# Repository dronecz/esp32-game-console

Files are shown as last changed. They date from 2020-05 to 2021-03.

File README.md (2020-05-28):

# ESP32 game console 

You can read more about my project [here](https://hackaday.io/project/166873-esp32-game-console) at Hackaday.io . :slightly_smiling_face:

This repository contain PCB files and 3D files for ESP32 game console. 

In case that you will have any question, you can contact me at info@czechmaker.com

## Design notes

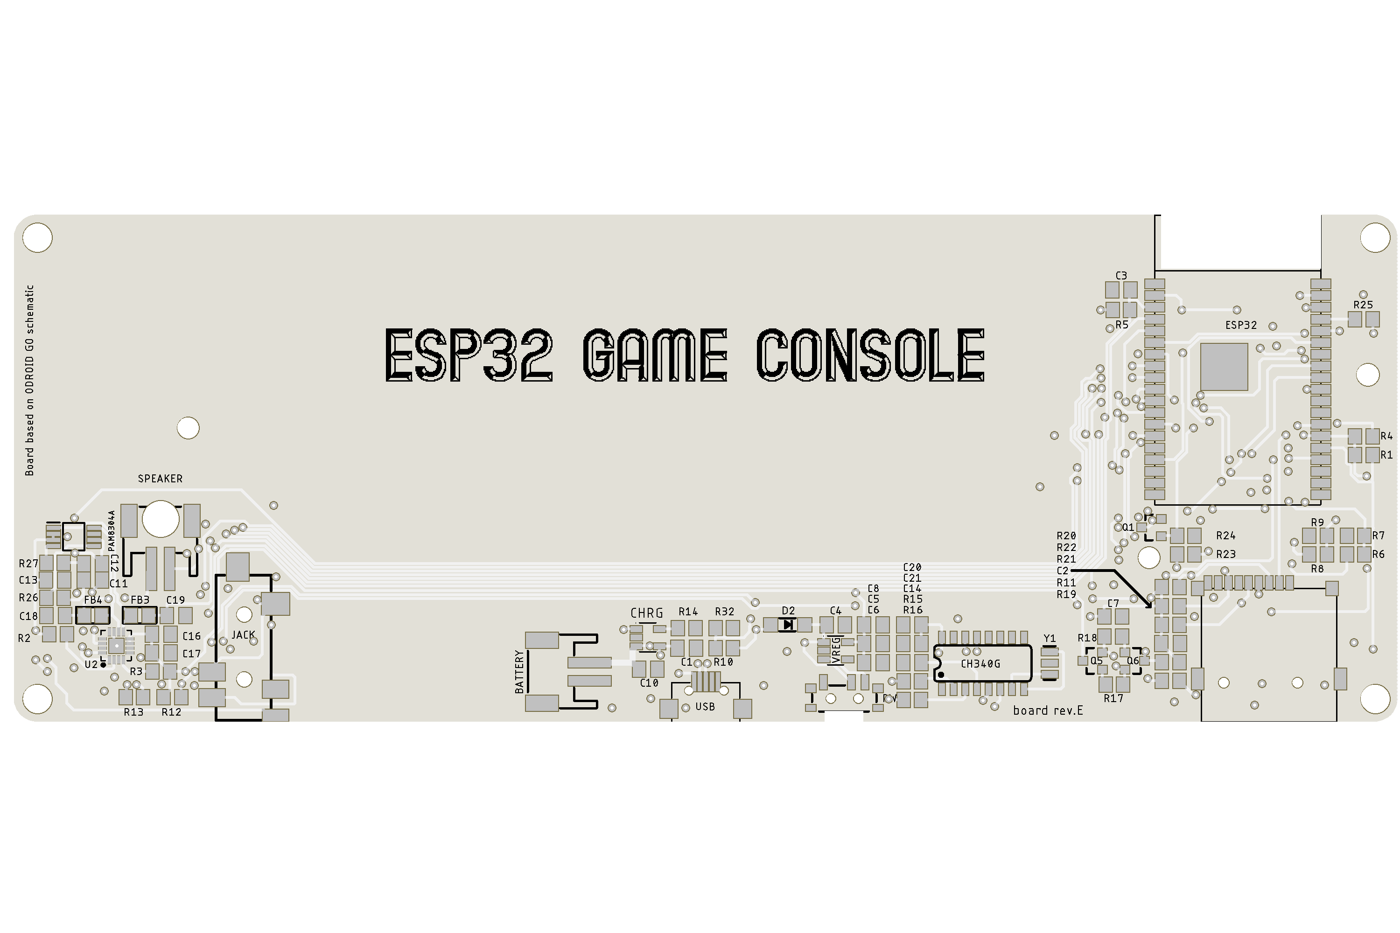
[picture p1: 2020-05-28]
PCB/rev_E_buttons/o_clone_rev_e_bottom.png

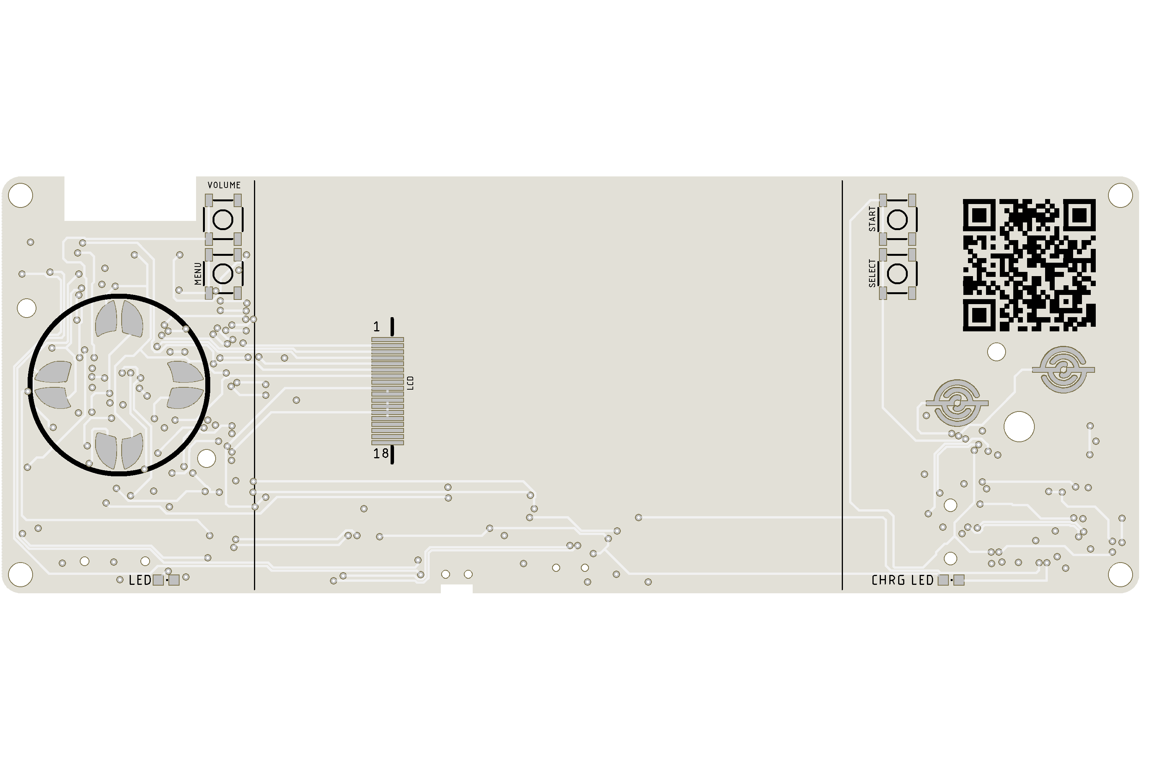
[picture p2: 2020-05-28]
PCB/rev_E_buttons/o_clone_rev_e_top.png

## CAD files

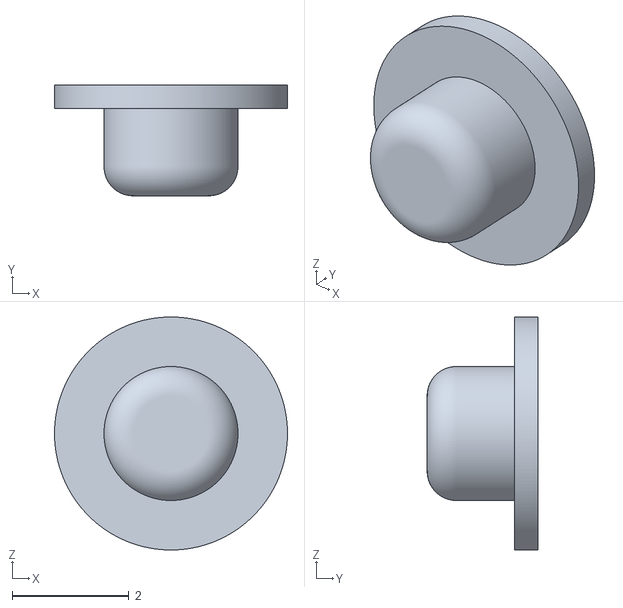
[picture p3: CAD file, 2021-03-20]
3D files/rev_F/esp32_gc_power_button_rev_F.stl
4.00 x 1.90 x 4.00

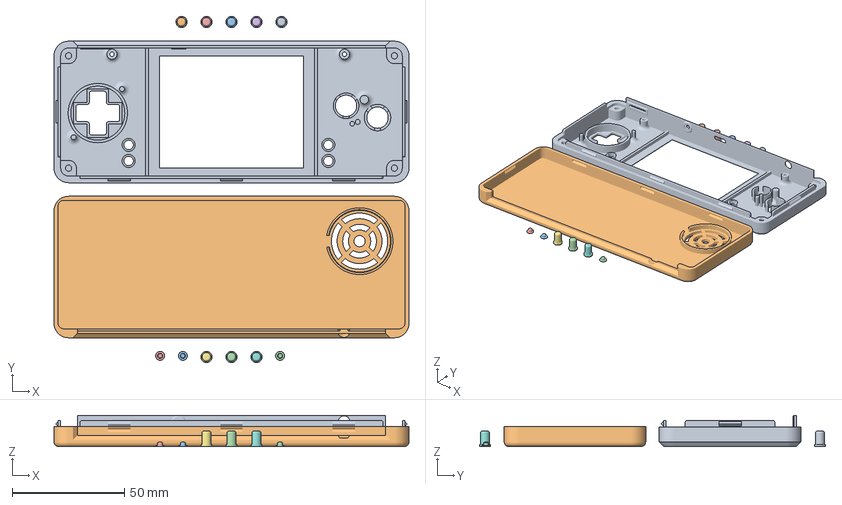
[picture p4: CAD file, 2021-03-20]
3D files/rev_F/Case_Odroid_Go_clone_rev_F.3mf
158.0 x 154.1 x 13.8 mm
top_case.stl
bottom_case.stl
eps32_gc_button_rev_F.stl
power_button.stl

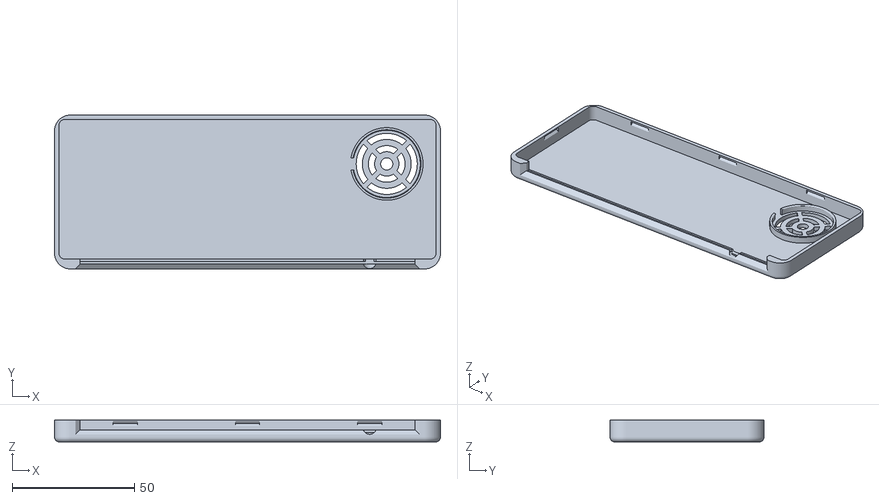
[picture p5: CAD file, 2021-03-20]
3D files/rev_F/esp32_gc_bottom_case_rev_F.stl
158.0 x 63.0 x 9.00

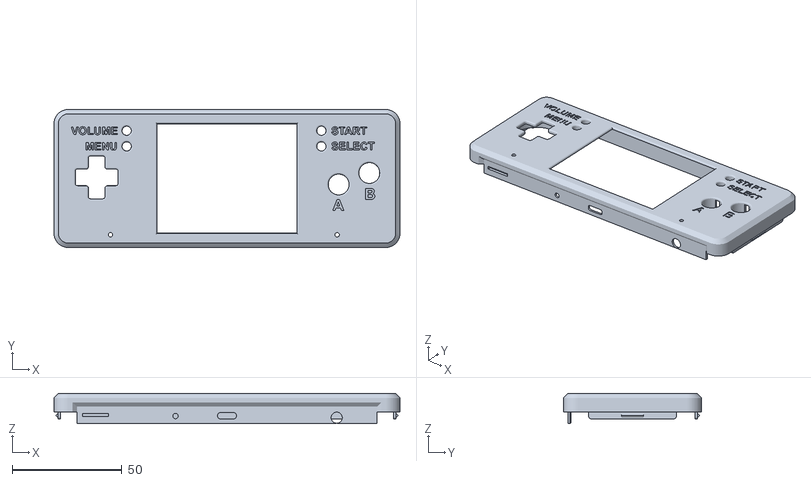
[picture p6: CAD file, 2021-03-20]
3D files/rev_F/esp32_gc_top_case_rev_F_letters.stl
158.0 x 63.0 x 13.8

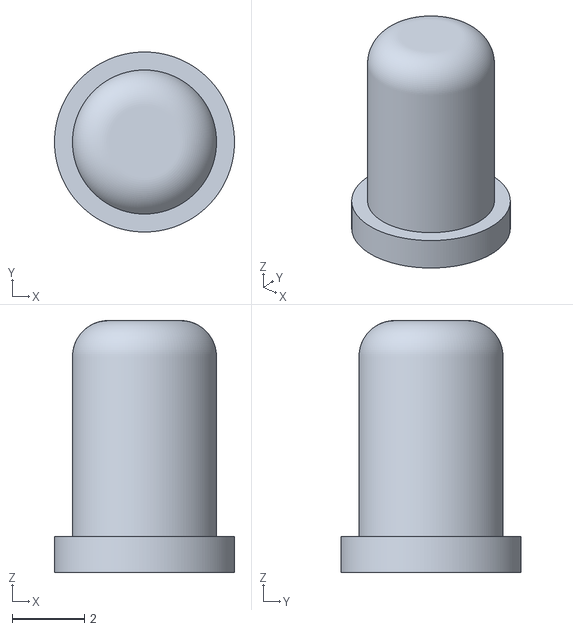
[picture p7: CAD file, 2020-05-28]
3D files/rev_F/eps32_gc_button_rev_F.stl
5.00 x 5.00 x 7.00

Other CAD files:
3D files/rev_F/esp32_gc_top_case_rev_F.stl

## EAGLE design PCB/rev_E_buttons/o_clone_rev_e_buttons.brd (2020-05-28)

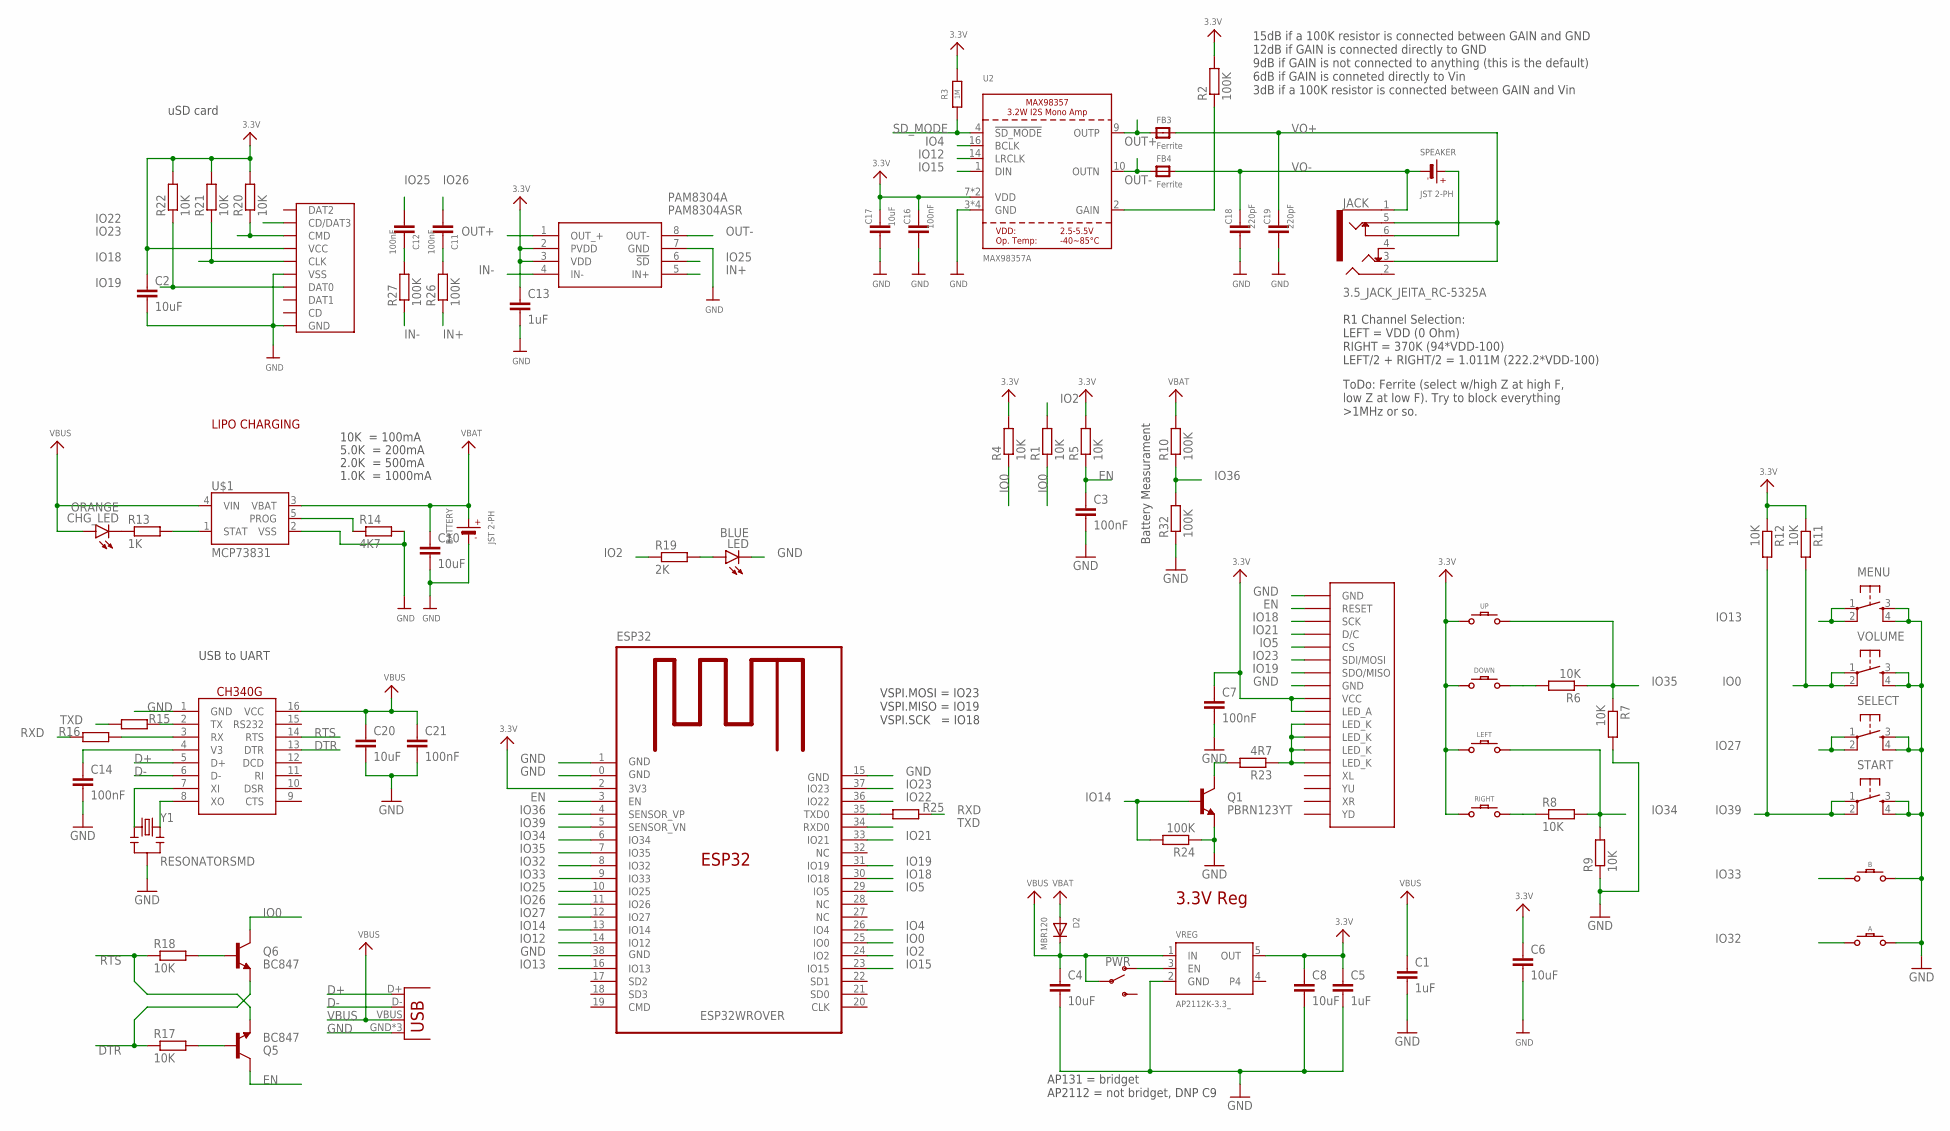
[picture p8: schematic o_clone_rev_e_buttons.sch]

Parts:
A: CONDUCTIVE_BUTTONCONDUCTIVE_BUTTON_THICK; CONDUCTIVE_BUTTON_THICK
B: CONDUCTIVE_BUTTONCONDUCTIVE_BUTTON_THICK; CONDUCTIVE_BUTTON_THICK
BATTERY: JST 2-PH; JSTPH2
C1, C5, C13: 1uF; C0805K
C2, C4, C6, C8, C10, C17, C20: 10uF; C0805K
C3, C11, C12, C14, C16, C21: 100nF; C0805K
C7: 100nF; C0805
C18, C19: 220pF; C0805K
CHG_LED: ORANGE; CHIPLED_0805
D2: MBR120; SOD-123
DOWN: CONDUCTIVE_BUTTONCONDUCTIVE_BUTTON_DIRECTIONAL_TH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; CONDUCTIVE_BUTTON_DIRECTIONAL_THICK
ESP32: ESP32WROVER
FB3, FB4: Ferrite; 0805
JACK: 3.5_JACK_JEITA_RC-5325A
LCD: ILI9341_3.2LCD_; LI9341_3.2LCD
LED: BLUE; CHIPLED_0805
LEFT: CONDUCTIVE_BUTTONCONDUCTIVE_BUTTON_DIRECTIONAL_TH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; CONDUCTIVE_BUTTON_DIRECTIONAL_THICK
MENU: TACTILE_SWITCHE_5X5_MICRO"; TACTILE_SWITCH_5X5_MICRO
PAM8304A: PAM8304ASR; SOP65P490X110-8N
PWR: SWITCH-SPDT-SMD-RIGHT-ANGLE; SWITCH_SPST_SMD_A
Q1: PBRN123YT; SOT23-3
Q5, Q6: BC847; SOT23-3
R1, R4, R5, R6, R7, R8, R9, R11, R12, R17, R18, R20, R21, R22: 10K; R0805
R2, R10, R24, R26, R27, R32: 100K; R0805
R3: 1M; R0805
R13: 1K; R0805
R14: 4K7; R0805
R15, R16, R25: 470R; R0805
R19: 2K; R0805
R23: 4R7; R0805
RIGHT: CONDUCTIVE_BUTTONCONDUCTIVE_BUTTON_DIRECTIONAL_TH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; CONDUCTIVE_BUTTON_DIRECTIONAL_THICK
SD_CARD: MICRO_SD_CARD"; TFP09-2--12B
SELECT: TACTILE_SWITCHE_5X5_MICRO"; TACTILE_SWITCH_5X5_MICRO
SPEAKER: JST 2-PH; JSTPH2
START: TACTILE_SWITCHE_5X5_MICRO"; TACTILE_SWITCH_5X5_MICRO
U2: MAX98357A; QFN16_3MM
U$1: MCP73831; SOT95P290X120-5
U$23: CH340G; SO16
UP: CONDUCTIVE_BUTTONCONDUCTIVE_BUTTON_DIRECTIONAL_TH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; CONDUCTIVE_BUTTON_DIRECTIONAL_THICK
USB: USB_MICRO_ATTEND_; USB_MICRO
VOLUME: TACTILE_SWITCHE_5X5_MICRO"; TACTILE_SWITCH_5X5_MICRO
VREG: AP2112K-3.3_; SOT95P290X120-5
Y1: RESONATORSMD; RESONATOR-SMD

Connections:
3.3V: C2.1, C5.1, C6.1, C7.1, C8.1, C13.1, C16.1, C17.1, DOWN.P$GND, ESP32.2 (3V3), LCD.P$9 (VCC), LCD.P$10 (LED_A), LEFT.P$GND, PAM8304A.2 (PVDD), PAM8304A.3 (VDD), R2.2, R3.2, R4.2, R5.2, R11.1, R12.1, R20.2, R21.2, R22.2, RIGHT.P$GND, SD_CARD.VCC, U2.7 (VDD), U2.8 (VDD), UP.P$GND, VREG.5 (OUT)
D+: U$23.5 (D+), USB.D+
D-: U$23.6 (D-), USB.D-
DTR: Q6.2 (E), R17.1, U$23.13 (DTR)
EN: C3.1, ESP32.3 (EN), LCD.P$2 (RESET), Q5.3 (C), R5.1
GND: A.P$ACTIVE, B.P$ACTIVE, BATTERY.1 (-), C1.2, C2.2, C3.2, C4.2, C5.2, C6.2, C7.2, C8.2, C10.2, C13.2, C14.2, C16.2, C17.2, C18.2, C19.2, C20.2, C21.2, ESP32.0 (GND), ESP32.1 (GND), ESP32.15 (GND), ESP32.38 (GND), LCD.P$1 (GND), LCD.P$8 (GND), LED.C, MENU.3, MENU.4, PAM8304A.7 (GND), Q1.2 (E), R7.2, R9.1, R14.2, R24.1, R32.1, SD_CARD.GND, SD_CARD.GND@1 (GND), SD_CARD.GND@2 (GND), SD_CARD.GND@3 (VSS), SD_CARD.VSS (GND), SELECT.3, SELECT.4, START.3, START.4, U2.3 (GND), U2.11 (GND), U2.15 (GND), U2.THERMAL (GND), U$1.2 (VSS), U$23.1 (GND), USB.GND, USB.GND@2 (GND), USB.GND@3 (GND), VOLUME.3, VOLUME.4, VREG.2 (GND), Y1.2
IN+: PAM8304A.5 (IN+), R26.1
IN-: PAM8304A.4 (IN-), R27.1
IO0: ESP32.25 (IO0), Q6.3 (C), R1.1, R4.1, R11.2, VOLUME.1, VOLUME.2
IO2: ESP32.24 (IO2), R1.2, R19.1
IO4: ESP32.26 (IO4), U2.16 (BCLK)
IO5: ESP32.29 (IO5), LCD.P$5 (CS)
IO12: ESP32.14 (IO12), U2.14 (LRCLK)
IO13: ESP32.16 (IO13), MENU.1, MENU.2
IO14: ESP32.13 (IO14), Q1.1 (B), R24.2
IO15: ESP32.23 (IO15), U2.1 (DIN)
IO18: ESP32.30 (IO18), LCD.P$3 (SCK), R21.1, SD_CARD.CLK
IO19: ESP32.31 (IO19), LCD.P$7 (SDO/MISO), R22.1, SD_CARD.DAT0
IO21: ESP32.33 (IO21), LCD.P$4 (D/C)
IO22: ESP32.36 (IO22), SD_CARD.CD/DAT3
IO23: ESP32.37 (IO23), LCD.P$6 (SDI/MOSI), R20.1, SD_CARD.CMD
IO25: C12.2, ESP32.10 (IO25), PAM8304A.6 (!SD)
IO26: C11.2, ESP32.11 (IO26)
IO27: ESP32.12 (IO27), SELECT.1, SELECT.2
IO32: A.P$GND, ESP32.8 (IO32)
IO33: B.P$GND, ESP32.9 (IO33)
IO34: ESP32.6 (IO34), LEFT.P$ACTIVE, R8.2, R9.2
IO35: ESP32.7 (IO35), R6.1, R7.1, UP.P$ACTIVE
IO36: ESP32.4 (SENSOR_VP), R10.1, R32.2
IO39: ESP32.5 (SENSOR_VN), R12.2, START.1, START.2
unnamed: ESP32.35 (TXD0), R25.2
unnamed: R8.1, RIGHT.P$ACTIVE
unnamed: PWR.1 (O), VREG.3 (EN)
unnamed: DOWN.P$ACTIVE, R6.2
unnamed: Q1.3 (C), R23.2
unnamed: LED.A, R19.2
unnamed: R2.1, U2.2 (GAIN)
unnamed: U$23.8 (XO), Y1.3
unnamed: C11.1, R26.2
unnamed: JACK.6, SPEAKER.2 (+)
unnamed: U$23.7 (XI), Y1.1
unnamed: LCD.P$11 (LED_K), LCD.P$12 (LED_K), LCD.P$13 (LED_K), LCD.P$14 (LED_K), R23.1
unnamed: CHG_LED.C, R13.1
unnamed: C12.1, R27.2
unnamed: C14.1, U$23.4 (V3)
unnamed: R15.1, U$23.2 (TX)
unnamed: R16.1, U$23.3 (RX)
unnamed: Q5.1 (B), R17.2
unnamed: Q6.1 (B), R18.2
unnamed: R13.2, U$1.1 (STAT)
unnamed: R14.1, U$1.5 (PROG)
OUT+: FB3.1, PAM8304A.1 (OUT_+), U2.9 (OUTP)
OUT-: FB4.1, PAM8304A.8 (OUT-), U2.10 (OUTN)
RTS: Q5.2 (E), R18.1, U$23.14 (RTS)
RXD: R16.2, R25.1
SD_MODE: R3.1, U2.4 (!SD_MODE)
TXD: ESP32.34 (RXD0), R15.2
VBAT: BATTERY.2 (+), C10.1, D2.A, R10.2, U$1.3 (VBAT)
VBUS: C1.1, C4.1, C20.1, C21.1, CHG_LED.A, D2.C, PWR.2, U$1.4 (VIN), U$23.16 (VCC), USB.VBUS, VREG.1 (IN)
VO+: C19.1, FB3.2, JACK.3, JACK.5
VO-: C18.1, FB4.2, JACK.1, SPEAKER.1 (-)

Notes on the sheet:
10K = 100mA
5.0K = 200mA
2.0K = 500mA
1.0K = 1000mA
LIPO CHARGING
USB to UART
Battery Measurament
3.3V Reg
uSD card
VSPI.MOSI = IO23 VSPI.MISO = IO19 VSPI.SCK = IO18
AP131 = bridget AP2112 = not bridget, DNP C9
R1 Channel Selection: LEFT = VDD (0 Ohm) RIGHT = 370K (94*VDD-100) LEFT/2 + RIGHT/2 = 1.011M (222.2*VDD-100)
ToDo: Ferrite (select w/high Z at high F, low Z at low F). Try to block everything >1MHz or so.
15dB if a 100K resistor is connected between GAIN and GND 12dB if GAIN is connected directly to GND 9dB if GAIN is not connected to anything (this is the default) 6dB if GAIN is conneted directly to Vin 3dB if a 100K resistor is connected between GAIN and Vin

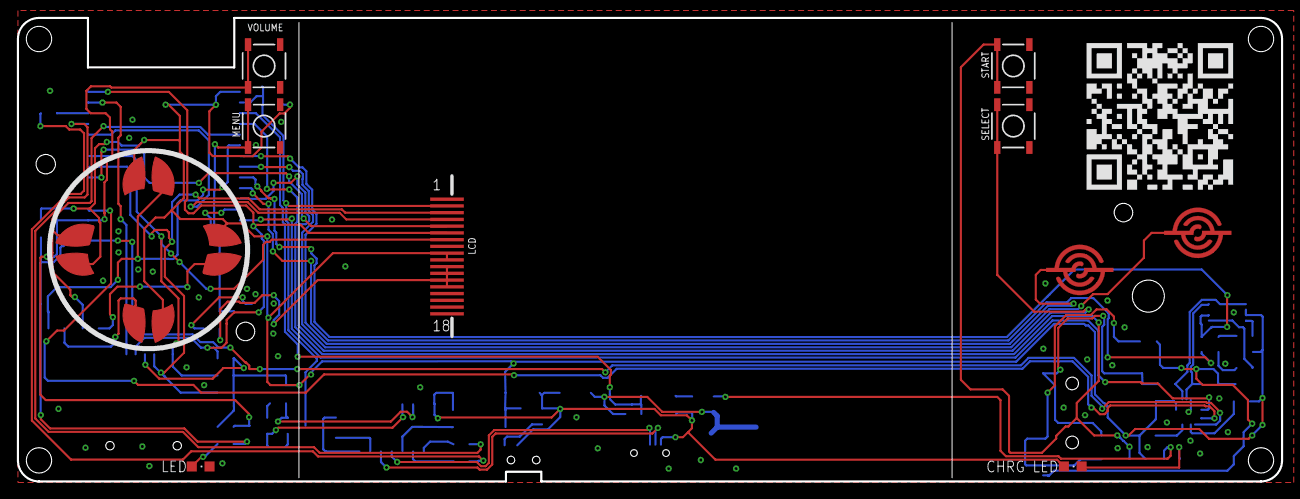
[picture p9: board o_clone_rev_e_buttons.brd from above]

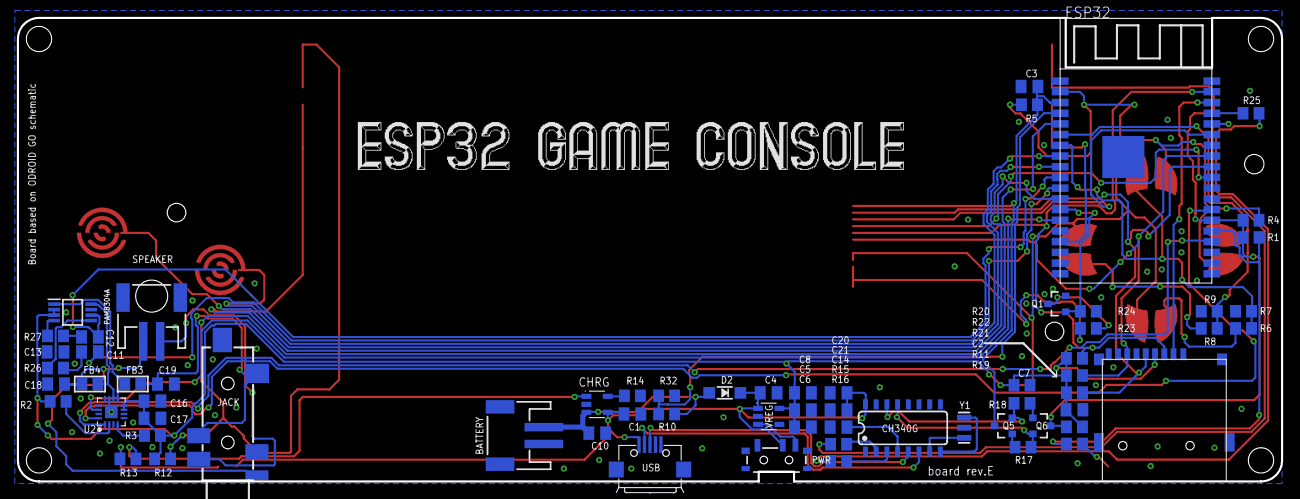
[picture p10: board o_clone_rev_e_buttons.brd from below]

Board: 2 copper layers, 150.0 x 55.0 mm, 79 parts (66 on the bottom side), 61 nets.

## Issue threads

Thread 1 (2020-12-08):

Can you share the firmware？

jianjinliao, 2020-12-08:
hi,Can you share the firmware? i like this project

dronecz, 2020-12-08:
Hi @jianjinliao ,

this use stock FW for Odroid Go so search for that one 😉 .

jianjinliao, 2020-12-08:
Hi dronecz ,Can you give an address?

dronecz, 2020-12-08:
Sure 🙂 Best to start here: https://wiki.odroid.com/odroid_go/odroid_go

jianjinliao, 2020-12-08:
Thank you very much, I look at

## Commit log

2020-05-28 Initial commit
    - PCB files (all versions)
    - 3D files (rev. F)
    [eps32_gc_button_rev_F.stl, esp32_gc_bottom_case_rev_F.stl, esp32_gc_power_button_rev_F.stl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]
2021-03-20 Update
    - added 3mf file for PrusaSlicer with all parts
    - redesigned case and changed files to the latest design
    [Case_Odroid_Go_clone_rev_F.3mf, esp32_gc_bottom_case_rev_F.stl, esp32_gc_power_button_rev_F.stl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]

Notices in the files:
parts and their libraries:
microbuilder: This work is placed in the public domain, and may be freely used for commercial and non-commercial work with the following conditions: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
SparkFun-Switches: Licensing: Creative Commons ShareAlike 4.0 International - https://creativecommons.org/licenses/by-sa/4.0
